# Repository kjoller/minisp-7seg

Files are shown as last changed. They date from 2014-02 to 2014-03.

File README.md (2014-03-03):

MiniSP-7seg
====================

A small (5x2½cm) MSP430G2xxx-board with a 4 digit 7 segment display.

Port 2 (and P1.0) is used for the seven digit display through a 
74HC595 shift register, leaving P1.1-P1.7 for other uses. The anode of the 
display digits are connected via transistors to PWM pins, allowing the
brightness to be adjusted

There is a 4 pin SBW programming header on the one side, and a breakout
for the serial out from the shift register - useful for adding another,
external shift register

R1-R8 is noted as 150R in the schematic, but can be anywhere from 100R to 1K.
Brightness can be adjusted this way.

The colon on the seven segment display can be activated (taking up P1.3) by 
adding R14 and R15.

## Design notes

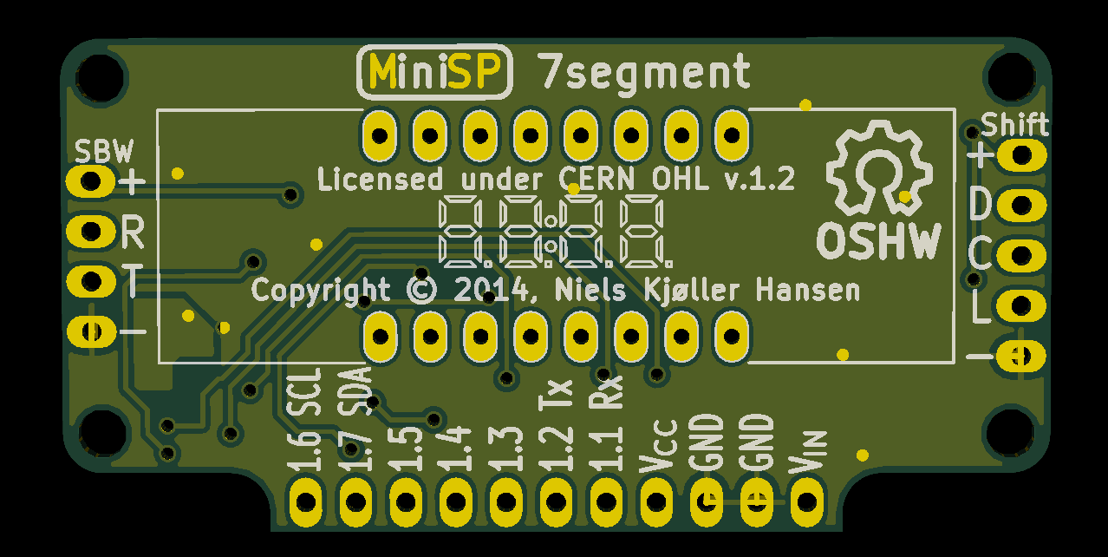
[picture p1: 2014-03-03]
msp-7seg-back.png

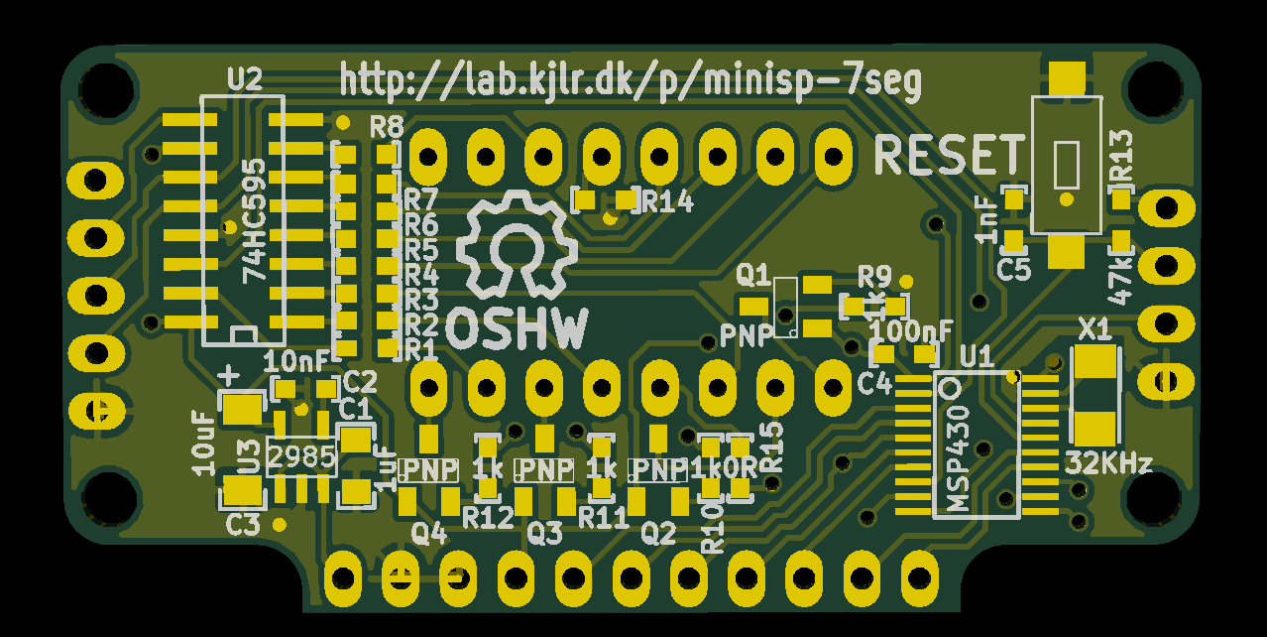
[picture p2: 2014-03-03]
msp-7seg-front.png

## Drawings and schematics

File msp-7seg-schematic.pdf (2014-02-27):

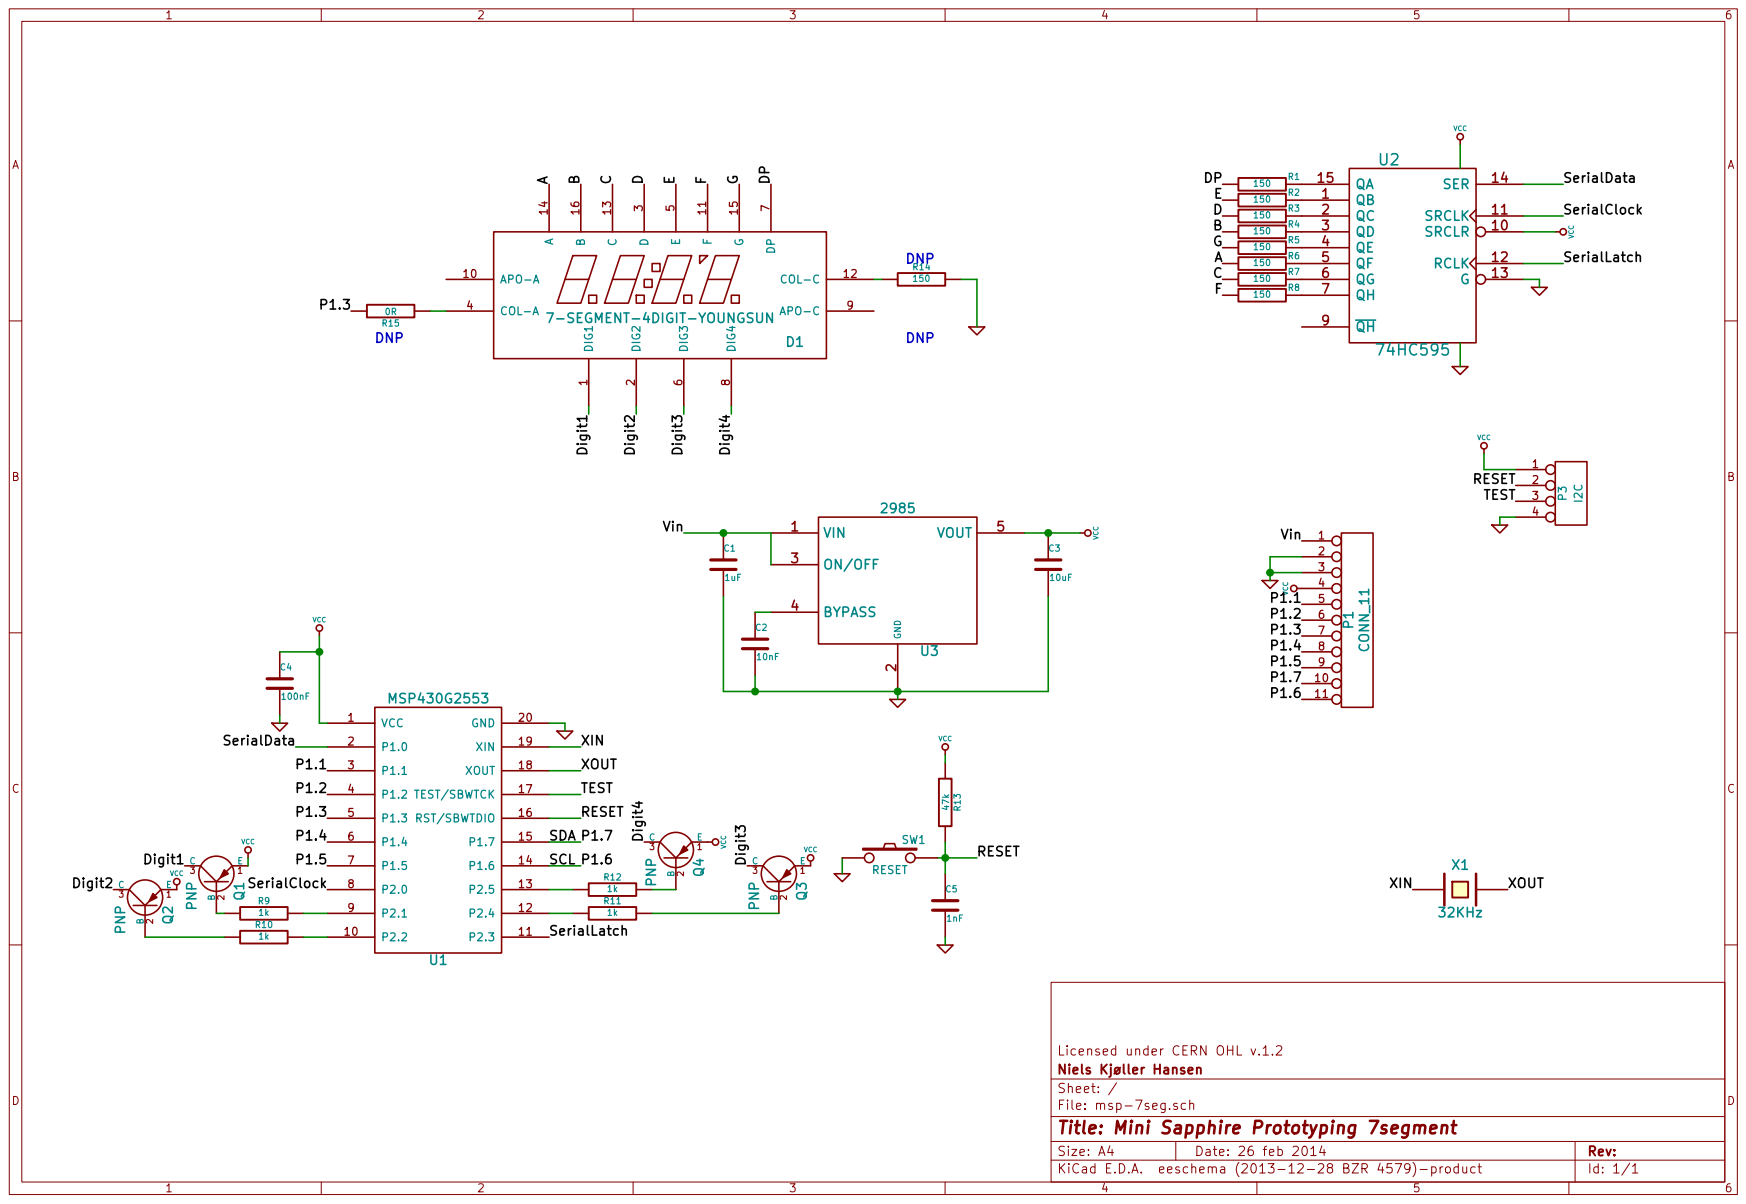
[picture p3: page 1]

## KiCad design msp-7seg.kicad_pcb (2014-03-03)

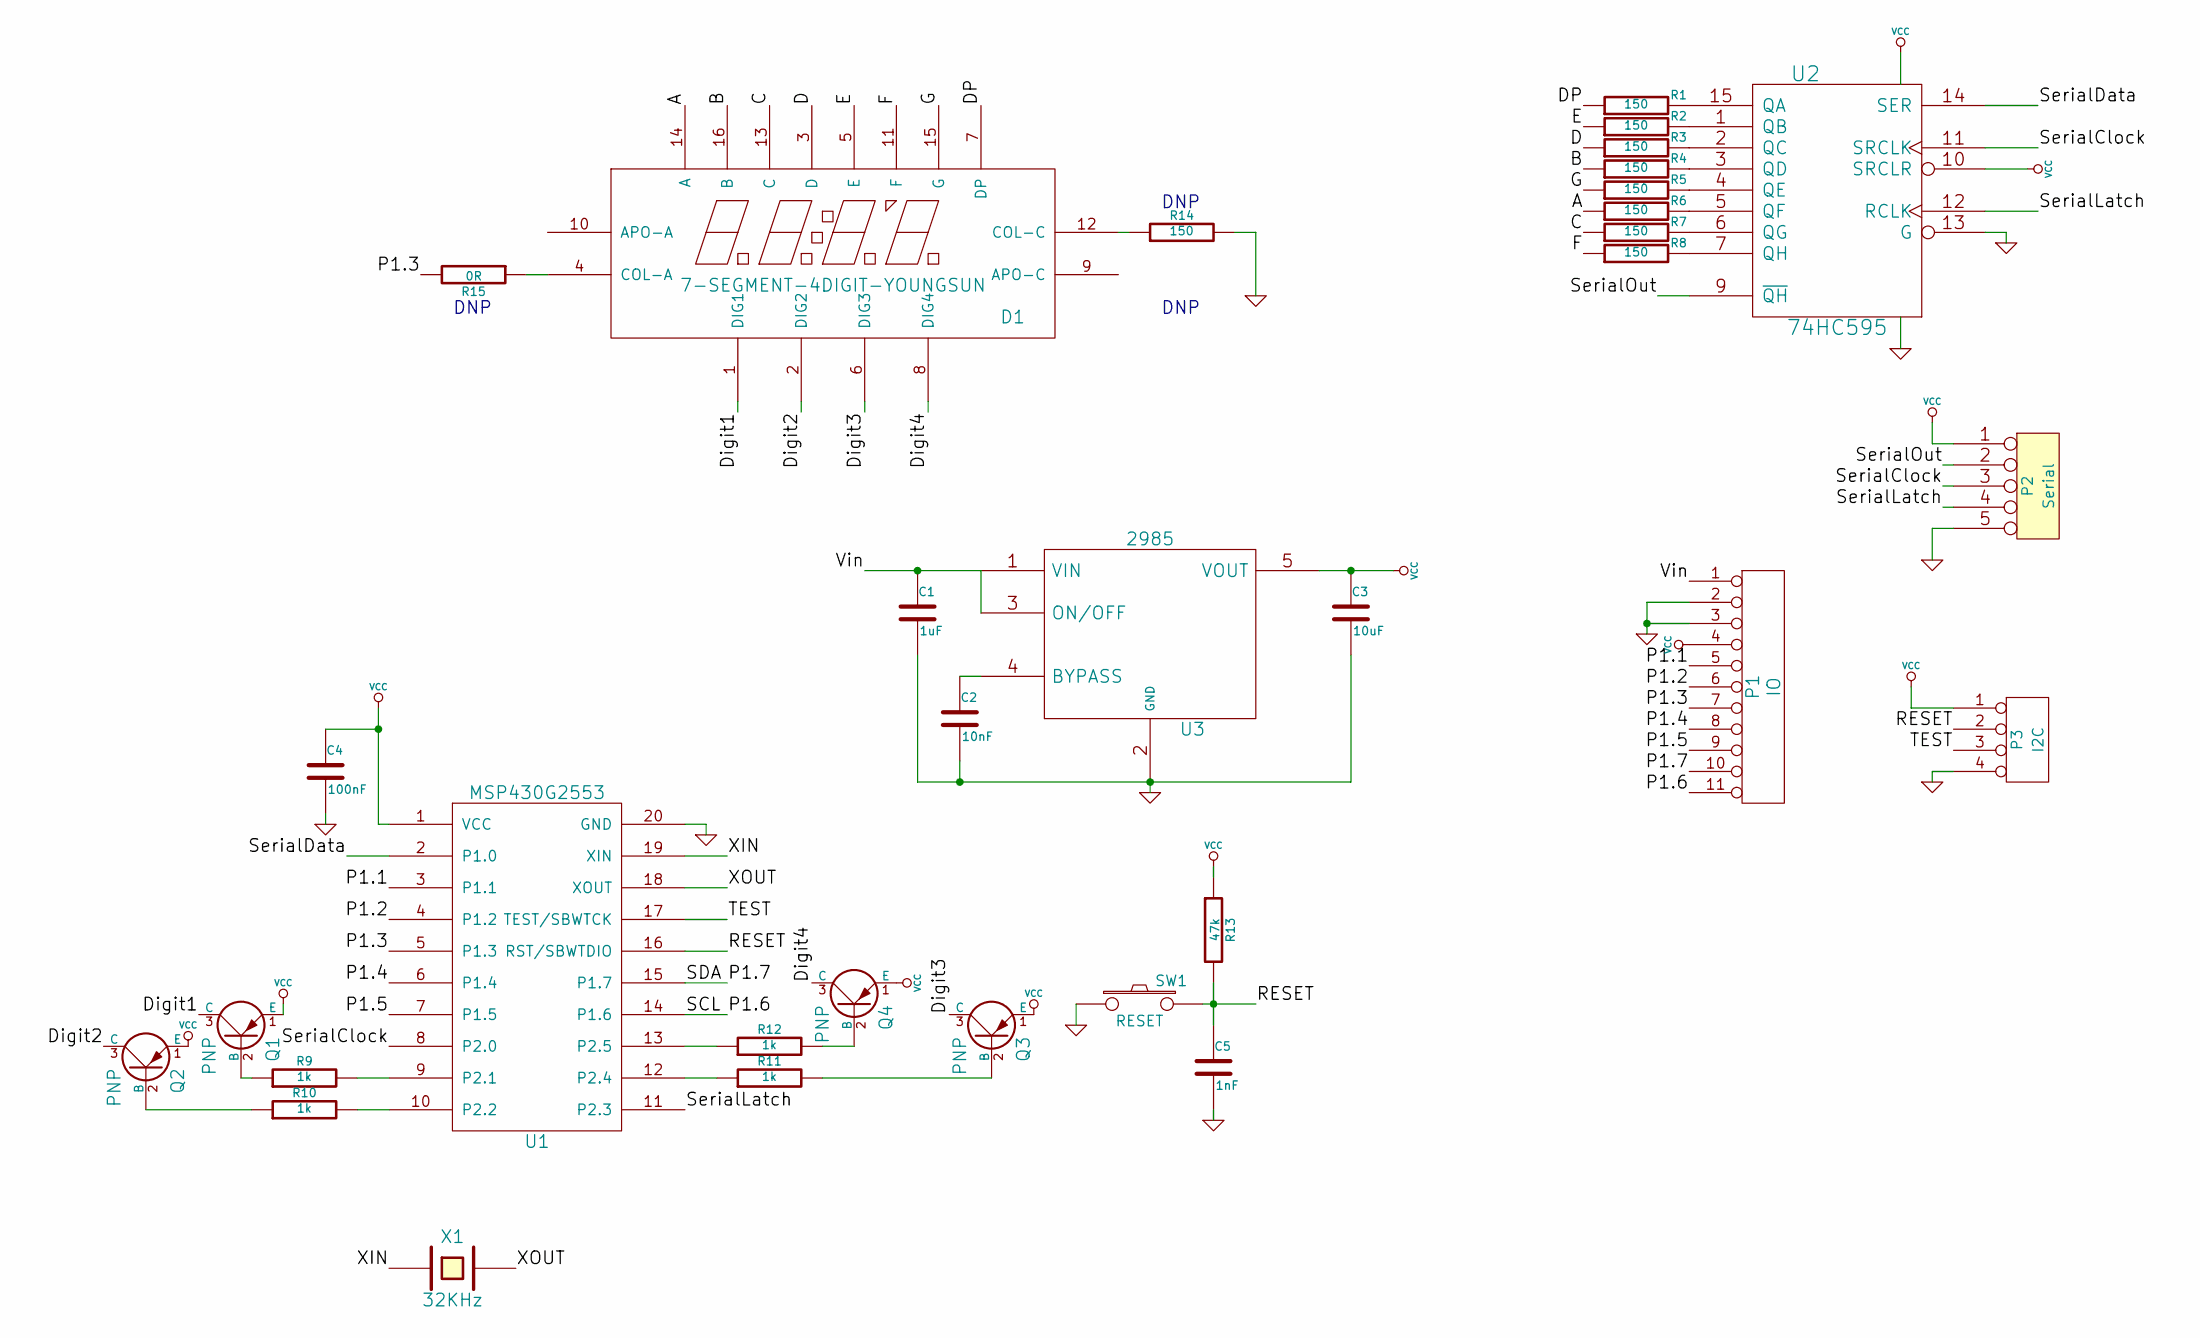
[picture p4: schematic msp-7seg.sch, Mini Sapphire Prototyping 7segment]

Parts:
C1: 1uF
C2: 10nF
C3: 10uF
C4: 100nF
C5: 1nF
D1: 7-SEGMENT-4DIGIT-YOUNGSUN
P1: IO
P2: Serial
P3: I2C
Q1, Q2, Q3, Q4: PNP
R1, R2, R3, R4, R5, R6, R7, R8, R14: 150
R9, R10, R11, R12: 1k
R13: 47k
R15: 0R
SW1: RESET
U1: MSP430G2553
U2: 74HC595
U3: 2985
X1: 32KHz

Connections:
/A: D1.14 (A), R6.1
/B: D1.16 (B), R4.1
/C: D1.13 (C), R7.1
/D: D1.3 (D), R3.1
/DP: D1.7 (DP), R1.1
/Digit1: D1.1 (DIG1), Q1.3 (C)
/Digit2: D1.2 (DIG2), Q2.3 (C)
/Digit3: D1.6 (DIG3), Q3.3 (C)
/Digit4: D1.8 (DIG4), Q4.3 (C)
/E: D1.5 (E), R2.1
/F: D1.11 (F), R8.1
/G: D1.15 (G), R5.1
/P1.1: P1.5, U1.3 (P1.1)
/P1.2: P1.6, U1.4 (P1.2)
/P1.3: P1.7, R15.2, U1.5 (P1.3)
/P1.4: P1.8, U1.6 (P1.4)
/P1.5: P1.9, U1.7 (P1.5)
/P1.6: P1.11, U1.14 (P1.6)
/P1.7: P1.10, U1.15 (P1.7)
/RESET: C5.1, P3.2, R13.2, SW1.2, U1.16 (RST/SBWTDIO)
/SerialClock: P2.3, U1.8 (P2.0), U2.11 (SRCLK)
/SerialData: U1.2 (P1.0), U2.14 (SER)
/SerialLatch: P2.4, U1.11 (P2.3), U2.12 (RCLK)
/SerialOut: P2.2, U2.9 (~QH)
/TEST: P3.3, U1.17 (TEST/SBWTCK)
/Vin: C1.1, P1.1, U3.1 (VIN), U3.3 (ON/OFF)
/XIN: U1.19 (XIN), X1.1
/XOUT: U1.18 (XOUT), X1.2
GND: C1.2, C2.2, C3.2, C4.2, C5.2, P1.2, P1.3, P2.5, P3.4, R14.2, SW1.1, U1.20 (GND), U2.8 (GND), U2.13 (G), U3.2 (GND)
unnamed: C2.1, U3.4 (BYPASS)
unnamed: D1.4 (COL-A), R15.1
unnamed: D1.12 (COL-C), R14.1
unnamed: Q1.2 (B), R9.1
unnamed: Q2.2 (B), R10.1
unnamed: Q3.2 (B), R11.2
unnamed: Q4.2 (B), R12.2
unnamed: R1.2, U2.15 (QA)
unnamed: R2.2, U2.1 (QB)
unnamed: R3.2, U2.2 (QC)
unnamed: R4.2, U2.3 (QD)
unnamed: R5.2, U2.4 (QE)
unnamed: R6.2, U2.5 (QF)
unnamed: R7.2, U2.6 (QG)
unnamed: R8.2, U2.7 (QH)
unnamed: R9.2, U1.9 (P2.1)
unnamed: R10.2, U1.10 (P2.2)
unnamed: R11.1, U1.12 (P2.4)
unnamed: R12.1, U1.13 (P2.5)
VCC: C3.1, C4.1, P1.4, P2.1, P3.1, Q1.1 (E), Q2.1 (E), Q3.1 (E), Q4.1 (E), R13.1, U1.1 (VCC), U2.10 (SRCLR), U2.16 (VCC), U3.5 (VOUT)

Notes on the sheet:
DNP

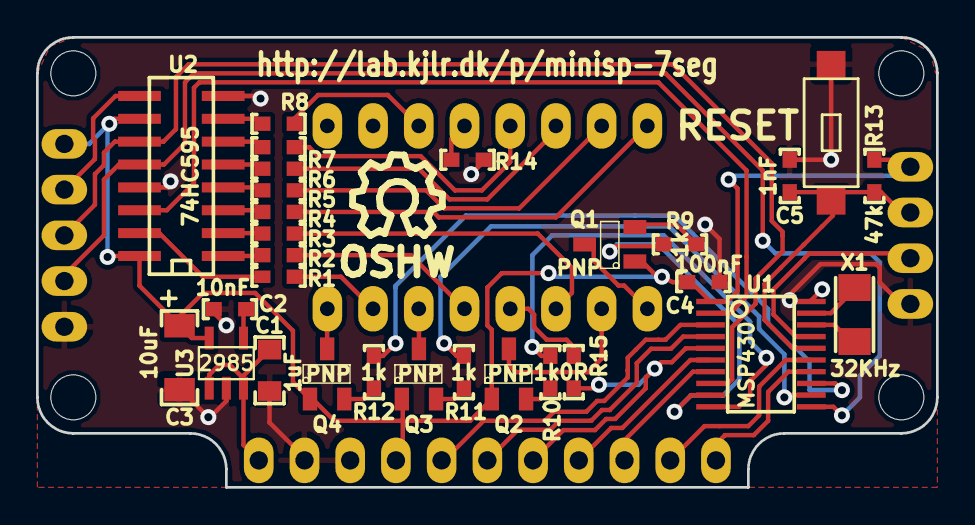
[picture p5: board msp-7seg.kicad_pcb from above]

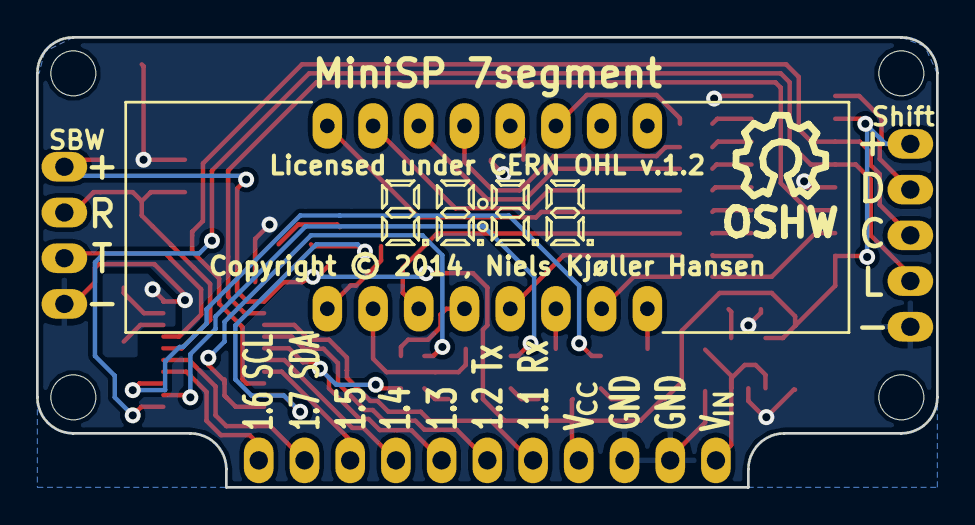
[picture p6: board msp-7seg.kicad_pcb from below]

Board: 2 copper layers, 50.0 x 25.0 mm, 39 parts (8 on the bottom side), 49 nets.

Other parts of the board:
MH: MountingHole_2-7mm_RevA_Date21Jun2010; MountingHole_2-5mm
MH#2, MH#3, MH#4: MountingHole_2-7mm_RevA_Date21Jun2010; MountingHole_2-5mm
SYM: Symbol_OSHW-Logo_SilkScreen_07Jul2012; Symbol_OSHW-Logo_SilkScreen
SYM#2: Symbol_OSHW-Logo_SilkScreen_07Jul2012; Symbol_OSHW-Logo_SilkScreen

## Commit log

2014-02-26 Initial commit - just missing a reset button
    [msp-7seg.kicad_pcb, msp-7seg.sch]
2014-02-26 Spread out components and added reset button
    [msp-7seg.kicad_pcb, msp-7seg.sch]
2014-02-27 Cleaned up silkscreen, added gerbers, schematic and images
    [msp-7seg-B_Cu.gbl, msp-7seg-B_Mask.gbs, msp-7seg-B_SilkS.gbo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]
2014-03-01 Added breakout for shift register
    [msp-7seg.kicad_pcb, msp-7seg.sch]
2014-03-03 Made a 5x5cm mini panel and added to the README.
    [msp-7seg-5x5panel-B_Cu.gbl, msp-7seg-5x5panel-B_Mask.gbs, msp-7seg-5x5panel-B_SilkS.gbo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]

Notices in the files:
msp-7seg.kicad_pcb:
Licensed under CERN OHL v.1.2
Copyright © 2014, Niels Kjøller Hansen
